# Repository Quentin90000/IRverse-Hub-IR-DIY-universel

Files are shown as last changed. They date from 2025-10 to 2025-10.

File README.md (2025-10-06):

# IRverse – Hub IR DIY universel

IRverse est un hub IR DIY basé sur ESP8266, capable de piloter tous vos appareils à télécommande infrarouge : TV, ampli, clim, hotte, sèche-serviettes, lumières IR, et plus.
Il apprend et reproduit vos codes IR, avec boîtiers modulables (LED haut/côté) et alimentation 5 V ou 230 V. Universel, flexible et 100 % DIY.

## **Fonctionnalités :**

- Apprentissage et reproduction de codes IR

- Pilotage de multiples appareils dans la même pièce

- Alimentation modulable : 5VDC USB externe ou 230VAC embarquée

- Boîtier modulable : LED pointant vers le haut ou sur le côté

- Compatible avec différents projets DIY et makers

## **Matériel nécessaire :**
**Microcontrôleur**

1 × **D1 Mini Pro 16 Mb avec antenne externe** – Gère l’émission IR et alimente tous les composants

### **Émission IR**

1 × **LED IR TSAL6400** – Pour émettre la lumière IR

1 × **Résistance 220 Ω** – Montage en série sur l’anode pour protéger la LED

### **Réception IR**

1 × **Résistance 10 kΩ** – Pull-up pour le TSOP38238

1 × **Récepteur IR TSOP38238** (ou équivalent)

### **Alimentation & découplage**

1 × **Condensateur 100 nF céramique** – Découplage et filtrage des hautes fréquences

1 × **Condensateur 100 µF électrolytique** – Stabilisation de l’alimentation

1 × **Module HLK-PM01** – Convertit 230 V AC en 5 V DC pour la version alimentation embarquée

### **Connectique & boîtier**

2 × **Borniers 2P 5.08 mm**

Câble 2G1.5 ou câble USB selon version

Presse-étoupe : PG9 pour alimentation embarquée, PG7 pour alimentation séparée

PCB sur mesure pour monter tous les composants proprement

## **Contenu du dépôt :**

Le dépôt contient tous les fichiers nécessaires pour le projet IRverse / IRfinity :

### **Boîtiers 3D**
- `IRverse - Alimentation embarquée.stl` – Boîtier avec LED vers le haut ou latérale et alimentation intégrée
- `IRverse - Alimentation séparée.stl` – Boîtier avec LED vers le haut ou latérale et alimentation séparée

### **Photos**
- `Boitier 3D IRverse - Alimentation embarquée.PNG` – Prototype avec alimentation intégrée
- `Boitier 3D IRverse - Alimentation séparée.PNG` – Prototype avec alimentation séparée
- `PCB IRverse - Alimentation embarquée.PNG` – PCB monté version alimentation intégrée
- `PCB IRverse - Alimentation séparée.PNG` – PCB monté version alimentation séparée
- `Shéma IRverse - Alimentation embarquée.PNG` – Schéma version alimentation intégrée
- `Shéma IRverse - Alimentation séparée.PNG` – Schéma version alimentation séparée
- `PCB IRverse - Alimentation embarquée assemblé.JPG` PCB IRverse - Alimentation intégrée assemblé

### **Fichiers PCB**
- `PCB IRverse - Alimentation embarquée.zip` – Gerbers version alimentation intégrée
- `PCB IRverse - Alimentation séparée.zip` – Gerbers version alimentation séparée

### **Code**
- `README.md` – Ce fichier

## **Code fonctionnel :**

Ici un code basé sur une hotte aspirante Roblin Aqua 900 :

```
esphome:
  name: esp8266-roblin-ir
  friendly_name: ESP8266-Roblin_IR

esp8266:
  board: d1_mini_pro

logger:

api:
  encryption:
    key: "tacléapi"

ota:
  platform: esphome
  password: "0a1abb4344477f1f0dd6a6e9c7143608"

wifi:
  ssid: "tonwifi"
  password: "tonmotdepasse"
  ap:
    ssid: "Esp8266-Roblin-Ir"
    password: "cvi91SvuVJfn"

captive_portal:

remote_transmitter:
  id: my_remote
  pin: D5
  carrier_duty_percent: 50%

# --- Récepteur IR pour sniffer ---
remote_receiver:
  pin:
    number: D4
    inverted: true
  dump: all

# --- Scripts pour appuis longs ---
script:
  - id: lumiere_min
    then:
      - delay: 3s
      - remote_transmitter.transmit_pronto:
          data: "0000 006D 000B 0000 0021 001A 001E 001A 001E 0019 003C 0034 001E 001A 001F 0019 001F 0019 001F 0019 001E 001B 001E 001A 001D 0181"

  - id: mode_24h_on
    then:
      - delay: 3s
      - remote_transmitter.transmit_pronto:
          data: "0000 006D 0009 0000 003E 0035 001E 0019 003B 0019 001E 0034 001F 001A 001E 001A 003B 0034 001F 001A 001E 0181"

  - id: mode_24h_off
    then:
      - delay: 3s
      - remote_transmitter.transmit_pronto:
          data: "0000 006D 0009 0000 003D 0034 001F 0019 003C 0019 001F 0034 001F 0019 001E 001A 003C 0035 001E 0019 001F 0181"

# --- Tous les boutons ---
button:
  # Lumière
  - platform: template
    name: "Lumière ON (max)"
    on_press:
      - remote_transmitter.transmit_pronto:
          data: "0000 006D 0009 0000 0021 0018 001F 0018 003C 0034 001E 001A 001E 001A 003B 006A 001E 001A 001E 001A 0057 0181"

  - platform: template
    name: "Lumière ON (min) - appui long"
    on_press:
      - script.execute: lumiere_min

  - platform: template
    name: "Lumière OFF"
    on_press:
      - remote_transmitter.transmit_pronto:
          data: "0000 006D 0009 0000 0021 0018 001F 0018 003C 0034 001E 001A 001E 001A 003A 006A 001E 001A 001E 001A 0057 0181"

  # Hotte
  - platform: template
    name: "Hotte ON"
    on_press:
      - remote_transmitter.transmit_pronto:
          data: "0000 006D 0009 0000 0021 0018 001F 0033 003C 001A 001E 001A 001E 0035 003B 004F 001E 0034 001E 001A 003B 0181"

  - platform: template
    name: "Hotte OFF"
    on_press:
      - remote_transmitter.transmit_pronto:
          data: "0000 006D 0009 0000 0021 0019 001F 0034 003C 0019 001F 0019 001F 0034 003B 004E 001F 0033 001F 001A 003B 0181"

  # Aspiration
  - platform: template
    name: "Aspiration +1"
    on_press:
      - remote_transmitter.transmit_pronto:
          data: "0000 006D 0008 0000 0021 0018 0059 0019 001E 001A 001E 001A 0057 001A 001E 004F 0057 0034 003B 0181"

  - platform: template
    name: "Aspiration -1"
    on_press:
      - remote_transmitter.transmit_pronto:
          data: "0000 006D 0008 0000 0021 0033 003C 0018 001F 0019 001E 0035 003B 001A 001E 006A 003B 0034 003B 0181"

  # Boost
  - platform: template
    name: "Boost ON"
    on_press:
      - remote_transmitter.transmit_pronto:
          data: "0000 006D 0008 0000 0021 0018 003C 0033 001F 001A 001E 001A 003B 0035 001E 004F 003B 004F 003B 0181"

  - platform: template
    name: "Boost OFF"
    on_press:
      - remote_transmitter.transmit_pronto:
          data: "0000 006D 0008 0000 0021 0019 003C 0033 001F 001A 001E 001A 003B 0034 001E 004F 003B 004F 003B 0181"

  # Arrêt différé
  - platform: template
    name: "Arrêt différé ON"
    on_press:
      - remote_transmitter.transmit_pronto:
          data: "0000 006D 0006 0000 0020 0034 003B 0034 001E 004F 003C 004F 001D 0034 003B 0181"

  - platform: template
    name: "Arrêt différé OFF"
    on_press:
      - remote_transmitter.transmit_pronto:
          data: "0000 006D 0006 0000 0021 0034 003B 0034 001F 004E 003B 004E 001E 0034 003C 0181"

  # Mode 24H
  - platform: template
    name: "Mode 24H ON - appui long"
    on_press:
      - script.execute: mode_24h_on

  - platform: template
    name: "Mode 24H OFF - appui long"
    on_press:
      - script.execute: mode_24h_off

  # Réserve / Inconnu
  - platform: template
    name: "Réserve / Inconnu"
    on_press:
      - remote_transmitter.transmit_pronto:
          data: "0000 006D 0009 0000 0021 0018 001F 0033 001F 0018 001F 0034 001E 0034 001E 0034 001E 001A 001E 0034 001E 0181"
```

## **Boîtiers 3D :**

- Base commune pour toutes les variantes

- Top interchangeable : LED vers le haut ou sur le côté

- Alimentation intégrée ou externe selon la version

- Les fichiers STL sont fournis dans le dossier

## **Licence :**

Ce projet est sous MIT License – vous êtes libre de l’utiliser, modifier et partager.

## **Lien externe :**

Le projet peut être suivi directement sur le forum HACF en suivant ce lien : https://forum.hacf.fr/t/emetteur-recepteur-irverse/65450

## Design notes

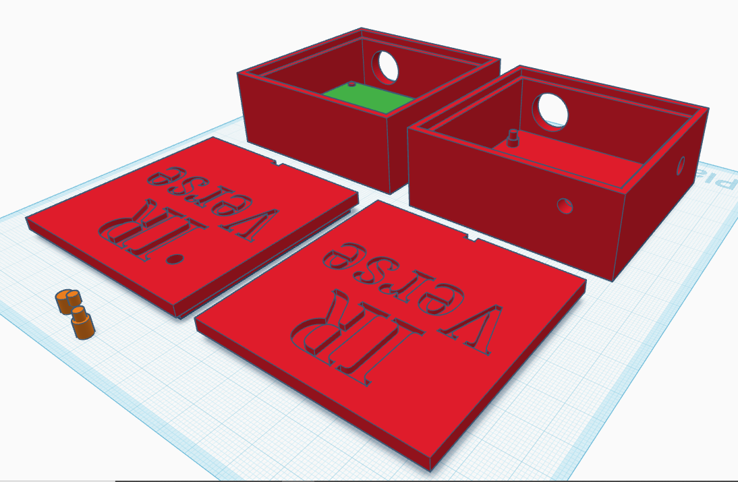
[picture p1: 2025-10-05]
Boitier 3D IRverse - Alimentation embarquée.PNG

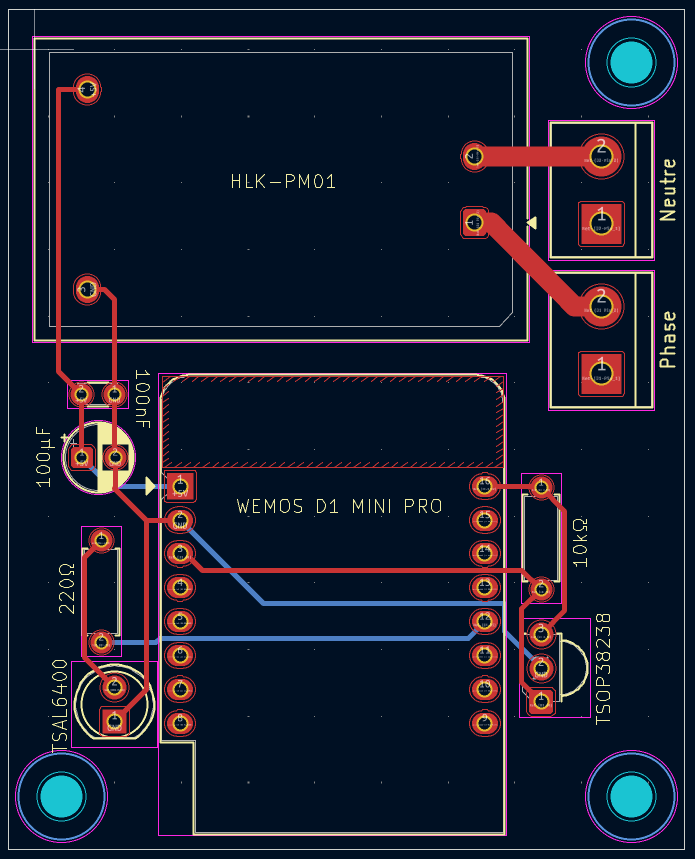
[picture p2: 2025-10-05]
PCB IRverse - Alimentation embarquée.PNG

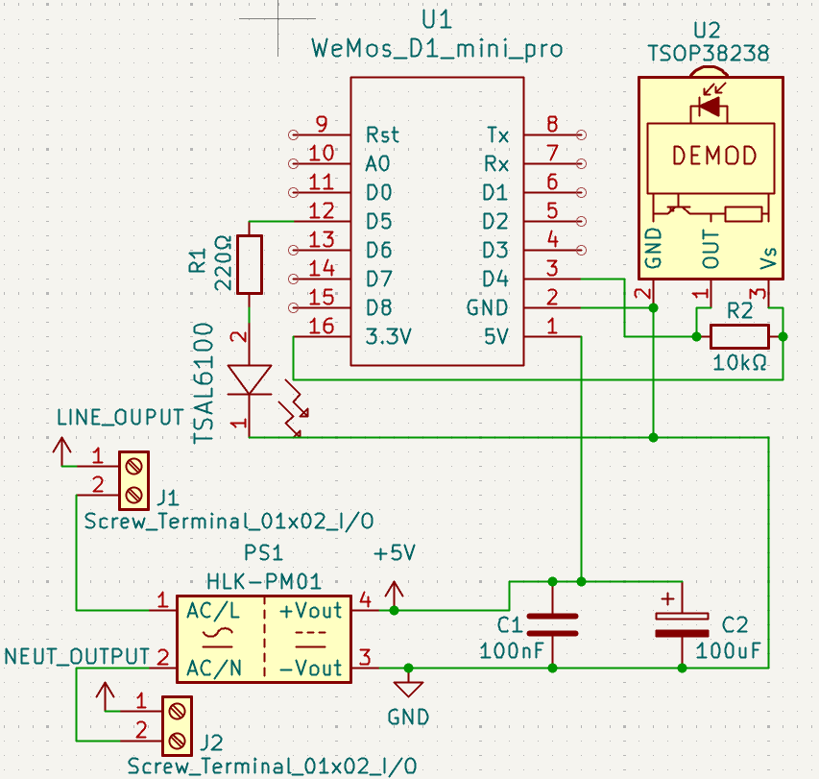
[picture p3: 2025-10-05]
Shéma IRverse - Alimentation embarquée.PNG

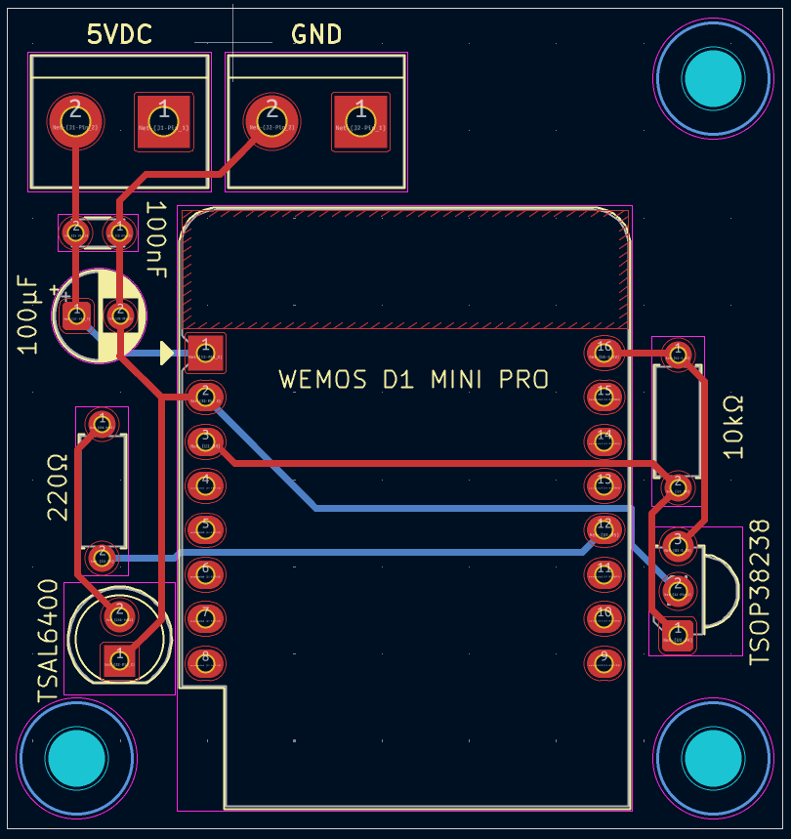
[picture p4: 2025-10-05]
PCB IRverse - Alimentation séparée.PNG

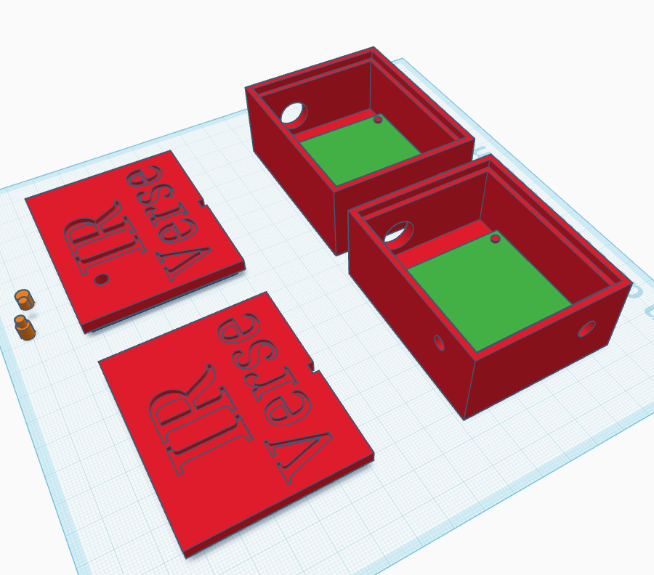
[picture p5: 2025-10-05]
Boitier 3D IRverse - Alimentation séparée.PNG

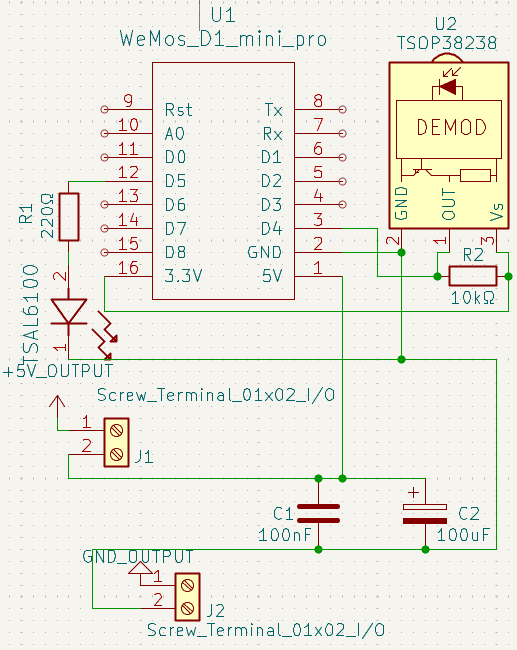
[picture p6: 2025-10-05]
Shéma IRverse - Alimentation séparée.PNG

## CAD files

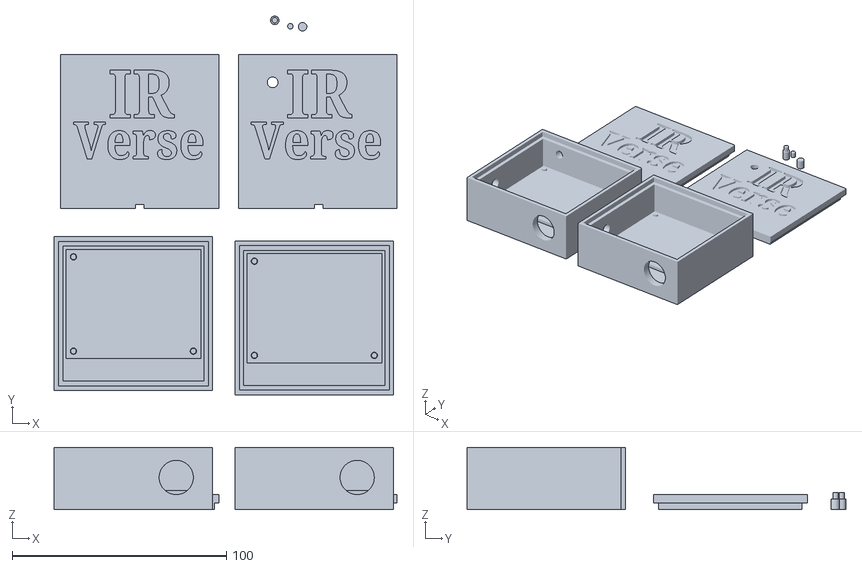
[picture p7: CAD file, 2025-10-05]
IRverse - Alimentation embarquée.stl
160.0 x 177.0 x 29.0

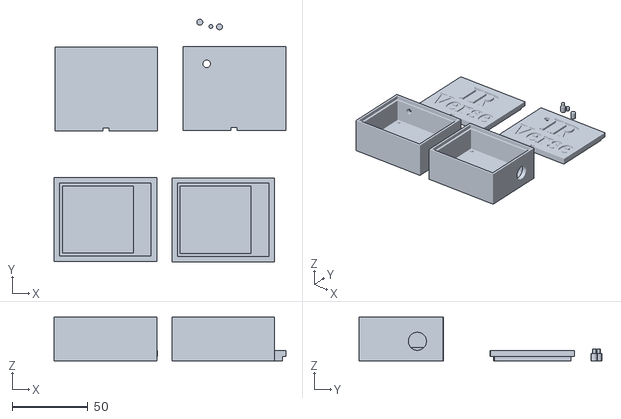
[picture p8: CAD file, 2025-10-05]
IRverse - Alimentation séparée.stl
153.5 x 160.5 x 29.0
